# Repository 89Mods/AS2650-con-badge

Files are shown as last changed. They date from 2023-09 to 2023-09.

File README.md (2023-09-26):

## AS2650 Con Badge

Repo containing all the files for my latest con badge, using one of my GFMPW-0 ICs.

`HW` contains the KiCad project for the hardware.

`NB_Firmware` contains the management controller firmware.

`CPLD` contains the Quartus project for the CPLD on the board.

`Verilog` contains a complete Verilog model of the whole board, including the LED screen (requires gtkmm-4.0 to display).

`Software` is the actual meat of the project - all the code running on the badge.

`Bitmaps` contains all image assets to be placed into ROM.

Some misc stuff:

`ObjParser.java` converts .obj 3D model files to the format used by my rasterizer implementation.

`ROM_layout` visualizes the layout of the SPI flash accessible by the AS2650.

`ROMGlue` is a very long script that grabs all the different built binaries and asset files, and puts it also into a single ROM image, according to the documented layout.

`Avali.bin` is the 3D model data rendered by one of the demos.

There is also a (very ugly) Makefile to build parts of the project.

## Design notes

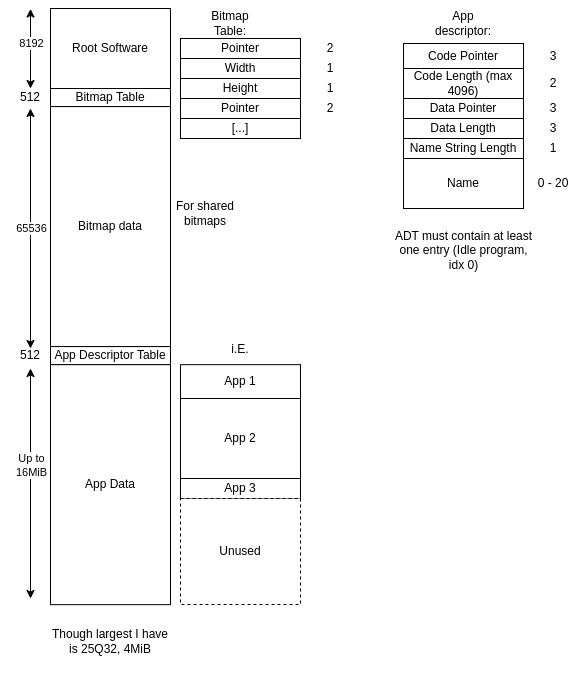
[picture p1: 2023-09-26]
ROM_layout.drawio.png

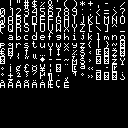
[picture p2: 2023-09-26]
Bitmaps/font.png

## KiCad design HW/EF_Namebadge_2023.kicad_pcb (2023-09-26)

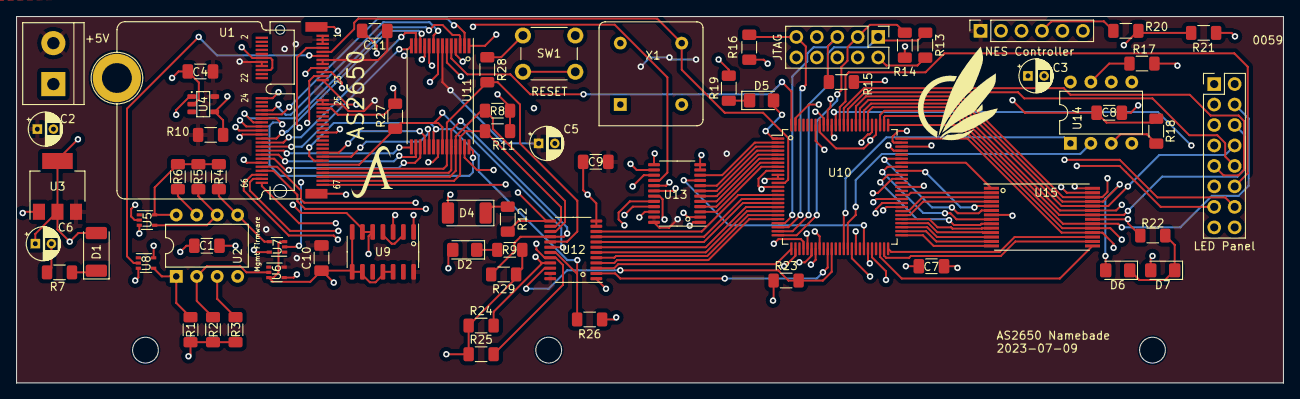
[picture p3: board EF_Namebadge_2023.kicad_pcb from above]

Board: 4 copper layers, 157.2 x 45.5 mm, 71 parts (0 on the bottom side), 124 nets.

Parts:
C1, C4, C7, C8, C9, C10, C11: 0.1µF; C_1206_3216Metric_Pad1.33x1.80mm_HandSolder
C2, C5, C6: 1µF; CP_Radial_D4.0mm_P2.00mm
C3: 10µF; CP_Radial_D4.0mm_P2.00mm
D1, D4: LED; LED_2010_5025Metric_Pad1.52x2.65mm_HandSolder
D2, D5, D6, D7: LED; LED_1206_3216Metric_Pad1.42x1.75mm_HandSolder
H1: MICROMOD-Standoff; MicroMod-Standoff
H2, H3, H4: MountingHole; MountingHole_3.2mm_M3_ISO7380
J1: Screw_Terminal_01x02; TerminalBlock_bornier-2_P5.08mm
J2: JTAG; PinHeader_2x05_P2.54mm_Vertical
J3: LED Panel; PinHeader_2x08_P2.54mm_Vertical
J4: NES Controller; PinSocket_1x06_P2.54mm_Vertical
R1, R2, R4, R5: 100K; R_1206_3216Metric_Pad1.30x1.75mm_HandSolder
R3, R6, R7, R8, R9, R10, R11, R12, R13, R14, R15, R16, R17, R18, R23, R24, R25, R26, R27, R28, R29: 10K; R_1206_3216Metric_Pad1.30x1.75mm_HandSolder
R19, R20, R21, R22: 1K; R_1206_3216Metric_Pad1.30x1.75mm_HandSolder
SW1: SW_Push; SW_PUSH_6mm
U1: AS2650; M.2-CONNECTOR-E
U2, U14: W25Q32FVSS; DIP-8_W7.62mm
U3: AMS1117-3.3; SOT-223-3_TabPin2
U4: MCP1319MT-29LE-OT; PoR_5_SOT23
U5, U6, U7, U8: SN74LV1T34DCK; SOT-353_SC-70-5
U9: 74HC02; SOIC-14_3.9x8.7mm_P1.27mm
U10: EPM240T100; LQFP-100_14x14mm_P0.5mm
U11: AS7C256; TSOP-I-28_11.8x8mm_P0.55mm
U12, U13: SN74LVC8T245; TSSOP-24_4.4x7.8mm_P0.65mm
U15: 61LV256; TSOP-I-28_11.8x8mm_P0.55mm
X1: 25MHz; Oscillator_DIP-8

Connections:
+3V3: C1.1, C3.1, C6.1, C7.2, C8.2, D1.2 (A), J2.4, R1.2, R2.2, R3.2, R4.2, R5.2, R6.2, R14.2, R15.2, R16.2, R17.1, R18.2, R23.1, U2.8 (VCC), U3.2 (VO), U5.5 (VCC), U7.5 (VCC), U8.5 (VCC), U10.9 (VCCIO1), U10.13 (VCCINT), U10.31 (VCCIO1), U10.45 (VCCIO1), U10.59 (VCCIO2), U10.63 (VCCINT), U10.80 (VCCIO2), U10.94 (VCCIO2), U12.1 (Vcca), U13.1 (Vcca), U14.8 (VCC), U15.7 (Vdd), X1.8 (Vcc)
+5V: C2.1, C4.2, C5.1, C9.2, C10.2, C11.2, J1.2, J4.1, R10.2, U1.1 (vccd2), U1.3 (vddio), U1.5 (vdda), U1.13 (vdda2), U1.14 (vccd), U1.15 (vcdd), U1.16 (vddio), U1.33 (vdda1), U1.35 (vccd1), U3.3 (VI), U4.5 (VDD), U6.5 (VCC), U9.14 (VCC), U11.7 (Vcc), U12.23 (Vccb), U12.24 (Vccb), U13.23 (Vccb), U13.24 (Vccb)
A0: U1.62 (mprj_io[20]), U11.17 (A0)
A1: U1.60 (mprj_io[21]), U11.16 (A1)
A2: U1.58 (mprj_io[22]), U11.15 (A2)
A3: U1.56 (mprj_io[23]), U11.14 (A3)
A4: U1.54 (mprj_io[24]), U11.13 (A4)
A5: U1.52 (mprj_io[25]), U11.12 (A5)
A6: U1.50 (mprj_io[26]), U11.11 (A6)
A7: U1.48 (mprj_io[27]), U11.10 (A7)
A8: U1.46 (mprj_io[28]), U11.4 (A8)
A9: U1.44 (mprj_io[29]), U11.3 (A9)
A10: U1.42 (mprj_io[30]), U11.28 (A10)
A11: U1.40 (mprj_io[31]), U11.2 (A11)
A12: U1.38 (mprj_io[32]), U11.9 (A12), U13.16 (B6)
A12_3.3: U10.3 (IO1_3), U13.8 (A6)
A13: U10.100 (IO2_100), U11.5 (A13)
A14: U10.99 (IO2_99), U11.8 (A14)
BUS_DIR: U10.35 (IO1_35), U12.2 (DIR)
DB0: R24.2, U1.59 (mprj_io[5]_ser_rx), U11.18 (I/O0), U12.21 (B1)
DB0_3.3: U10.26 (IO1_26), U12.3 (A1)
DB1: R25.2, U1.61 (mprj_io[6]_ser_tx), U11.19 (I/O1), U12.20 (B2)
DB1_3.3: U10.21 (IO1_21), U12.4 (A2)
DB2: R26.2, U1.63 (mprj_io[7]), U11.20 (I/O2), U12.19 (B3)
DB2_3.3: U10.20 (IO1_20), U12.5 (A3)
DB3: R27.2, U1.65 (mprj_io[8]), U11.22 (I/O3), U12.18 (B4)
DB3_3.3: U10.19 (IO1_19), U12.6 (A4)
DB4: R28.2, U1.67 (mprj_io[9]), U11.23 (I/O4), U12.17 (B5)
DB4_3.3: U10.18 (IO1_18), U12.7 (A5)
DB5: R29.2, U1.69 (mprj_io[10]), U11.24 (I/O5), U12.16 (B6)
DB5_3.3: U10.17 (IO1_17), U12.8 (A6)
DB6: R8.2, U1.71 (mprj_io[11]), U11.25 (I/O6), U12.15 (B7)
DB6_3.3: U10.16 (IO1_16), U12.9 (A7)
DB7: R11.2, U1.73 (mprj_io[12]), U11.26 (I/O7), U12.14 (B8)
DB7_3.3: U10.15 (IO1_15), U12.10 (A8)
DISP_A: J3.10, U10.86 (IO2_86)
DISP_B: J3.9, U10.87 (IO2_87)
DISP_C: J3.12, U10.88 (IO2_88)
DISP_CLK: J3.14, U10.73 (IO2_73)
DISP_D: J3.11, U10.89 (IO2_89)
DISP_OE: J3.16, U10.74 (IO2_74)
DISP_STB: J3.13, U10.72 (IO2_72)
D/~C: U1.74 (mprj_io[14]), U13.21 (B1)
D/~C_3.3: U10.8 (IO1_8), U13.3 (A1)
FIRM_CS: R1.1, U2.1 (~CS), U8.4 (Y)
FIRM_SCK: R5.1, U2.6 (SCK), U5.4 (Y)
FIRM_SI: R4.1, U2.5 (SI(D0)), U7.4 (Y)
FIRM_SO: R2.1, U2.2 (SO(D1)), U6.2 (A)
Flag: D2.2 (A), U1.64 (mprj_io[19])
GND: C1.2, C2.2, C3.2, C4.1, C5.2, C6.2, C7.1, C8.1, C9.1, C10.1, C11.1, J1.1, J2.2, J2.10, J3.3, J3.7, J3.15, J4.5, J4.6, R7.2, R8.1, R9.2, R11.1, R12.2, R13.2, R19.2, R21.1, R22.2, R24.1, R25.1, R26.1, R27.1, R28.1, R29.1, SW1.1, U1.12 (GND), U1.18 (GND), U1.37 (GND), U1.A1 (GND), U1.A2 (GND), U2.4 (GND), U3.1 (GND), U4.2 (VSS), U5.3 (GND), U6.3 (GND), U7.3 (GND), U8.3 (GND), U9.7 (GND), U9.8, U9.9, U9.11, U9.12, U10.10 (GNDIO), U10.11 (GNDINT), U10.32 (GNDIO), U10.46 (GNDIO), U10.60 (GNDIO), U10.65 (GNDINT), U10.79 (GNDIO), U10.93 (GNDIO), U11.21 (GND), U12.11 (GND), U12.12 (GND), U12.13 (GND), U13.2 (DIR), U13.11 (GND), U13.12 (GND), U13.13 (GND), U13.22 (~OE), U14.4 (GND), U15.21 (GND), U15.27 (~CE), X1.4 (GND)
LVL_SHIFT_EN: R23.2, U10.36 (IO1_36), U12.22 (~OE)
M/~IO: U1.72 (mprj_io[15]), U13.20 (B2)
M/~IO_3.3: U10.7 (IO1_7), U13.4 (A2)
NES_CLK: J4.2, U10.29 (IO1_29)
NES_DATA: R20.1, R21.2, U10.33 (IO1_33)
NES_LATCH: J4.3, U10.30 (IO1_30)
unnamed: D1.1 (K), R7.1
unnamed: D2.1 (K), R9.1
unnamed: D4.1 (K), R12.1
unnamed: D5.2 (A), U10.1 (IO2_1)
unnamed: D5.1 (K), R19.1
unnamed: D6.1 (K), D7.1 (K), R22.1
unnamed: J2.1, R13.1, U10.24 (TCK)
unnamed: J2.3, R14.1, U10.25 (TDO)
unnamed: J2.5, R15.1, U10.22 (TMS)
unnamed: J2.9, R16.1, U10.23 (TDI)
unnamed: J4.4, R20.2
unnamed: U1.11 (Caravel_CSB), U8.2 (A)
unnamed: U1.17 (Caravel_D0), U7.2 (A)
unnamed: U1.19 (Caravel_D1), U6.4 (Y)
unnamed: U1.23 (Caravel_SCK), U5.2 (A)
unnamed: U1.7 (~RST), U9.1
unnamed: R6.1, U2.7 (~HOLD(D3))
unnamed: R3.1, U2.3 (~WP(D2))
unnamed: R10.1, SW1.2, U4.4 (~MR)
unnamed: U9.2, U9.4
unnamed: U10.2 (IO1_2), U13.10 (A8)
unnamed: R17.2, U14.7 (~HOLD(D3))
unnamed: R18.1, U14.3 (~WP(D2))
OPREQ: U1.68 (mprj_io[17]), U13.18 (B4)
OPREQ_3.3: U10.5 (IO1_5), U13.6 (A4)
POR: U4.1 (~RST), U9.5, U9.6, U13.15 (B7)
POR_3.3: U10.44 (IO1_44/DEV_CLRn), U13.9 (A7)
R/~W: U1.66 (mprj_io[18]), U13.17 (B5)
R/~W_3.3: U10.4 (IO1_4), U13.7 (A5)
SPI_SCK: U10.41 (IO1_41), U14.6 (SCK)
SPI_SI: U10.40 (IO1_40), U14.2 (SO(D1))
SPI_SO: U10.42 (IO1_42), U14.5 (SI(D0))
Sense: U1.75 (mprj_io[13]), U10.27 (IO1_27)
VRAM_AD0: U10.50 (IO1_50), U15.17 (A0)
VRAM_AD1: U10.49 (IO1_49), U15.16 (A1)
VRAM_AD2: U10.48 (IO1_48), U15.15 (A2)
VRAM_AD3: U10.51 (IO1_51), U15.14 (A3)
VRAM_AD4: U10.52 (IO2_52), U15.13 (A4)
VRAM_AD5: U10.53 (IO2_53), U15.12 (A5)
VRAM_AD6: U10.54 (IO2_54), U15.11 (A6)
VRAM_AD7: U10.55 (IO2_55), U15.10 (A7)
VRAM_AD8: U10.56 (IO2_56), U15.4 (A8)
VRAM_AD9: U10.57 (IO2_57), U15.3 (A9)
VRAM_AD10: U10.58 (IO2_58), U15.28 (A10)
VRAM_AD11: U10.61 (IO2_61), U15.2 (A11)
VRAM_AD12: U10.66 (IO2_66), U15.9 (A12)
VRAM_AD13: U10.67 (IO2_67), U15.5 (A13)
VRAM_AD14: U10.68 (IO2_68), U15.8 (A14)
VRAM_D0: J3.2, U10.75 (IO2_75), U15.18 (IO0)
VRAM_D1: J3.1, U10.76 (IO2_76), U15.19 (IO1)
VRAM_D2: J3.4, U10.77 (IO2_77), U15.20 (IO2)
VRAM_D3: J3.6, U10.78 (IO2_78), U15.22 (IO3)
VRAM_D4: J3.5, U10.81 (IO2_81), U15.23 (IO4)
VRAM_D5: J3.8, U10.82 (IO2_82), U15.24 (IO5)
VRAM_D6: D6.2 (A), U10.83 (IO2_83), U15.25 (IO6)
VRAM_D7: D7.2 (A), U10.84 (IO2_84), U15.26 (IO7)
WRP: U1.70 (mprj_io[16]), U13.19 (B3)
WRP_3.3: U10.6 (IO1_6), U13.5 (A3)
cpld_rst: U1.32 (mprj_io[35]), U13.14 (B8)
crvl_led: D4.2 (A), U1.49 (mprj_io[0])
gpio: U1.21 (gpio), U9.3
xclk: U1.9 (xclk), U10.12 (IO1_12/GCLK0), X1.5 (OUT)
~RAM_CE: U10.90 (IO2_90), U11.27 (~CE)
~RAM_OE: U10.91 (IO2_91), U11.1 (~OE)
~RAM_WE: U10.92 (IO2_92), U11.6 (~WE)
~SPI_CS: U10.39 (IO1_39), U14.1 (~CS)
~VRAM_OE: U10.69 (IO2_69), U15.1 (~OE)
~VRAM_WE: U10.70 (IO2_70), U15.6 (~WE)

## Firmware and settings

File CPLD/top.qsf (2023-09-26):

# -------------------------------------------------------------------------- #
#
# Copyright (C) 2023  Intel Corporation. All rights reserved.
# Your use of Intel Corporation's design tools, logic functions 
# and other software and tools, and any partner logic 
# functions, and any output files from any of the foregoing 
# (including device programming or simulation files), and any 
# associated documentation or information are expressly subject 
# to the terms and conditions of the Intel Program License 
# Subscription Agreement, the Intel Quartus Prime License Agreement,
# the Intel FPGA IP License Agreement, or other applicable license
# agreement, including, without limitation, that your use is for
# the sole purpose of programming logic devices manufactured by
# Intel and sold by Intel or its authorized distributors.  Please
# refer to the applicable agreement for further details, at
# https://fpgasoftware.intel.com/eula.
#
# -------------------------------------------------------------------------- #
#
# Quartus Prime
# Version 22.1std.1 Build 917 02/14/2023 SC Lite Edition
# Date created = 17:04:29  June 30, 2023
#
# -------------------------------------------------------------------------- #
#
# Notes:
#
# 1) The default values for assignments are stored in the file:
#		top_assignment_defaults.qdf
#    If this file doesn't exist, see file:
#		assignment_defaults.qdf
#
# 2) Intel recommends that you do not modify this file. This
#    file is updated automatically by the Quartus Prime software
#    and any changes you make may be lost or overwritten.
#
# -------------------------------------------------------------------------- #


set_global_assignment -name FAMILY "MAX II"
set_global_assignment -name DEVICE EPM240T100C5
set_global_assignment -name TOP_LEVEL_ENTITY top
set_global_assignment -name ORIGINAL_QUARTUS_VERSION 22.1STD.1
set_global_assignment -name PROJECT_CREATION_TIME_DATE "17:04:29  JUNE 30, 2023"
set_global_assignment -name LAST_QUARTUS_VERSION "22.1std.2 Lite Edition"
set_global_assignment -name PROJECT_OUTPUT_DIRECTORY output_files
set_global_assignment -name MIN_CORE_JUNCTION_TEMP 0
set_global_assignment -name MAX_CORE_JUNCTION_TEMP 85
set_global_assignment -name DEVICE_FILTER_PACKAGE TQFP
set_global_assignment -name DEVICE_FILTER_PIN_COUNT 100
set_global_assignment -name ERROR_CHECK_FREQUENCY_DIVISOR "-1"
set_global_assignment -name POWER_EXT_SUPPLY_VOLTAGE_TO_REGULATOR 3.3V
set_location_assignment PIN_5 -to opreq
set_location_assignment PIN_4 -to rw
set_location_assignment PIN_6 -to wrp
set_location_assignment PIN_12 -to clk
set_location_assignment PIN_15 -to dbus[7]
set_location_assignment PIN_16 -to dbus[6]
set_location_assignment PIN_17 -to dbus[5]
set_location_assignment PIN_18 -to dbus[4]
set_location_assignment PIN_19 -to dbus[3]
set_location_assignment PIN_20 -to dbus[2]
set_location_assignment PIN_21 -to dbus[1]
set_location_assignment PIN_26 -to dbus[0]
set_instance_assignment -name IO_STANDARD "3.3-V LVTTL" -to A12
set_instance_assignment -name IO_STANDARD "3.3-V LVTTL" -to DISP_addr[1]
set_location_assignment PIN_3 -to A12
set_location_assignment PIN_100 -to A13
set_location_assignment PIN_99 -to A14
set_location_assignment PIN_86 -to DISP_addr[0]
set_location_assignment PIN_87 -to DISP_addr[1]
set_location_assignment PIN_88 -to DISP_addr[2]
set_location_assignment PIN_89 -to DISP_addr[3]
set_location_assignment PIN_73 -to DISP_clk
set_location_assignment PIN_74 -to DISP_oeb
set_location_assignment PIN_72 -to DISP_stb
set_location_assignment PIN_29 -to NES_clk
set_location_assignment PIN_33 -to NES_data
set_location_assignment PIN_91 -to RAM_oeb
set_location_assignment PIN_90 -to RAM_ceb
set_location_assignment PIN_92 -to RAM_web
set_location_assignment PIN_27 -to sense
set_location_assignment PIN_7 -to m_io
set_location_assignment PIN_36 -to lvl_shift_enb
set_location_assignment PIN_2 -to cpld_rst
set_location_assignment PIN_8 -to d_c
set_location_assignment PIN_35 -to bus_dir
set_location_assignment PIN_70 -to VRAM_web
set_location_assignment PIN_69 -to VRAM_oeb
set_location_assignment PIN_84 -to VRAM_data[7]
set_location_assignment PIN_83 -to VRAM_data[6]
set_location_assignment PIN_82 -to VRAM_data[5]
set_location_assignment PIN_81 -to VRAM_data[4]
set_location_assignment PIN_78 -to VRAM_data[3]
set_location_assignment PIN_77 -to VRAM_data[2]
set_location_assignment PIN_76 -to VRAM_data[1]
set_location_assignment PIN_75 -to VRAM_data[0]
set_location_assignment PIN_68 -to VRAM_addr[14]
set_location_assignment PIN_67 -to VRAM_addr[13]
set_location_assignment PIN_66 -to VRAM_addr[12]
set_location_assignment PIN_44 -to POR
set_location_assignment PIN_30 -to NES_latch
set_location_assignment PIN_39 -to SPI_csb
set_location_assignment PIN_41 -to SPI_sck
set_location_assignment PIN_40 -to SPI_si
set_location_assignment PIN_42 -to SPI_so
set_location_assignment PIN_61 -to VRAM_addr[11]
set_location_assignment PIN_58 -to VRAM_addr[10]
set_location_assignment PIN_57 -to VRAM_addr[9]
set_location_assignment PIN_56 -to VRAM_addr[8]
set_location_assignment PIN_55 -to VRAM_addr[7]
set_location_assignment PIN_54 -to VRAM_addr[6]
set_location_assignment PIN_53 -to VRAM_addr[5]
set_location_assignment PIN_52 -to VRAM_addr[4]
set_location_assignment PIN_51 -to VRAM_addr[3]
set_location_assignment PIN_48 -to VRAM_addr[2]
set_location_assignment PIN_49 -to VRAM_addr[1]
set_location_assignment PIN_50 -to VRAM_addr[0]
set_location_assignment PIN_1 -to LED
set_instance_assignment -name IO_STANDARD "3.3-V LVTTL" -to RAM_ceb
set_instance_assignment -name IO_STANDARD "3.3-V LVTTL" -to RAM_oeb
set_instance_assignment -name IO_STANDARD "3.3-V LVCMOS" -to RAM_web
set_instance_assignment -name IO_STANDARD "3.3-V LVCMOS" -to A13
set_instance_assignment -name IO_STANDARD "3.3-V LVCMOS" -to A14
set_instance_assignment -name IO_STANDARD "3.3-V LVTTL" -to dbus[7]
set_instance_assignment -name IO_STANDARD "3.3-V LVTTL" -to dbus[6]
set_instance_assignment -name IO_STANDARD "3.3-V LVTTL" -to dbus[5]
set_instance_assignment -name IO_STANDARD "3.3-V LVTTL" -to dbus[4]
set_instance_assignment -name IO_STANDARD "3.3-V LVTTL" -to dbus[3]
set_instance_assignment -name IO_STANDARD "3.3-V LVTTL" -to dbus[2]
set_instance_assignment -name IO_STANDARD "3.3-V LVTTL" -to dbus[1]
set_instance_assignment -name IO_STANDARD "3.3-V LVTTL" -to dbus
set_global_assignment -name SDC_FILE top.out.sdc
set_global_assignment -name VERILOG_FILE top.v
set_global_assignment -name POWER_PRESET_COOLING_SOLUTION "NO HEAT SINK WITH STILL AIR"

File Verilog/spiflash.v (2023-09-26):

`default_nettype none
/*
 *  SPDX-FileCopyrightText: 2017 Clifford Wolf
 *
 *  PicoSoC - A simple example SoC using PicoRV32
 *
 *  Copyright (C) 2017  Clifford Wolf <clifford@clifford.at>
 *
 *  Permission to use, copy, modify, and/or distribute this software for any
 *  purpose with or without fee is hereby granted, provided that the above
 *  copyright notice and this permission notice appear in all copies.
 *
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
 *  SPDX-License-Identifier: ISC
 */

`timescale 1 ns / 1 ps

//
// Simple SPI flash simulation model
//
// This model samples io input signals 1ns before the SPI clock edge and
// updates output signals 1ns after the SPI clock edge.
//
// Supported commands:
//    AB, B9, FF, 03, BB, EB, ED
//
// Well written SPI flash data sheets:
//    Cypress S25FL064L http://www.cypress.com/file/316661/download
//    Cypress S25FL128L http://www.cypress.com/file/316171/download
//

module spiflash #(
	parameter FILENAME = "../software.txt"
)(
	input csb,
	input clk,
	inout io0, // MOSI
	inout io1, // MISO
	inout io2,
	inout io3
);
	localparam verbose = 0;
	localparam integer latency = 8;
	
	reg [7:0] buffer;
	reg [3:0] reset_count = 0;
	reg [3:0] reset_monitor = 0;
	integer bitcount = 0;
	integer bytecount = 0;
	integer dummycount = 0;

	reg [7:0] spi_cmd;
	reg [7:0] xip_cmd = 0;
	reg [23:0] spi_addr;

	reg [7:0] spi_in;
	reg [7:0] spi_out;
	reg spi_io_vld;

	reg powered_up = 0;

	localparam [3:0] mode_spi         = 1;
	localparam [3:0] mode_dspi_rd     = 2;
	localparam [3:0] mode_dspi_wr     = 3;
	localparam [3:0] mode_qspi_rd     = 4;
	localparam [3:0] mode_qspi_wr     = 5;
	localparam [3:0] mode_qspi_ddr_rd = 6;
	localparam [3:0] mode_qspi_ddr_wr = 7;

	reg [3:0] mode = 0;
	reg [3:0] next_mode = 0;

	reg io0_oe = 0;
	reg io1_oe = 0;
	reg io2_oe = 0;
	reg io3_oe = 0;

	reg io0_dout = 0;
	reg io1_dout = 0;
	reg io2_dout = 0;
	reg io3_dout = 0;

	assign io0 = io0_oe ? io0_dout : 1'bz;
	assign io1 = io1_oe ? io1_dout : 1'bz;
	assign io2 = io2_oe ? io2_dout : 1'bz;
	assign io3 = io3_oe ? io3_dout : 1'bz;

	wire io0_delayed;
	wire io1_delayed;
	wire io2_delayed;
	wire io3_delayed;

	assign io0_delayed = io0;
	assign io1_delayed = io1;
	assign io2_delayed = io2;
	assign io3_delayed = io3;

	// 16 MB (128Mb) Flash
	reg [7:0] memory [0:16*1024*1024-1];

	initial begin
		//$display("Memory 5 bytes = 0x%02x 0x%02x 0x%02x 0x%02x 0x%02x",
		//	memory[1048576], memory[1048577], memory[1048578],
		//	memory[1048579], memory[1048580]);
		$display("Reading %s",  FILENAME);
		$readmemh(FILENAME, memory);
		$display("%s loaded into memory", FILENAME);
		$display("Memory 5 bytes = 0x%02x 0x%02x 0x%02x 0x%02x 0x%02x",
			memory[0], memory[1], memory[2],
			memory[3], memory[4]);
	end

	task spi_action;
		begin
			spi_in = buffer;

			if (bytecount == 1) begin
				spi_cmd = buffer;

				if (spi_cmd == 8'h ab)
					powered_up = 1;

				if (spi_cmd == 8'h b9)
					powered_up = 0;

				if (spi_cmd == 8'h ff)
					xip_cmd = 0;
				
			end
			if (spi_cmd == 8'h 90 && bytecount >= 4) buffer = 8'hAB; //Different ID from real chip, so CPU knows its in a simulation
			if (powered_up && spi_cmd == 'h 03) begin
				if (bytecount == 2)
					spi_addr[23:16] = buffer;

				if (bytecount == 3)
					spi_addr[15:8] = buffer;

				if (bytecount == 4)
					spi_addr[7:0] = buffer;

				if (bytecount >= 4) begin
					buffer = memory[spi_addr];
					spi_addr = spi_addr + 1;
				end
			end

			if (powered_up && spi_cmd == 'h bb) begin
				if (bytecount == 1)
					mode = mode_dspi_rd;

				if (bytecount == 2)
					spi_addr[23:16] = buffer;

				if (bytecount == 3)
					spi_addr[15:8] = buffer;

				if (bytecount == 4)
					spi_addr[7:0] = buffer;

				if (bytecount == 5) begin
					xip_cmd = (buffer == 8'h a5) ? spi_cmd : 8'h 00;
					mode = mode_dspi_wr;
					dummycount = latency;
				end

				if (bytecount >= 5) begin
					buffer = memory[spi_addr];
					spi_addr = spi_addr + 1;
				end
			end

			if (powered_up && spi_cmd == 'h eb) begin
				if (bytecount == 1)
					mode = mode_qspi_rd;

				if (bytecount == 2)
					spi_addr[23:16] = buffer;

				if (bytecount == 3)
					spi_addr[15:8] = buffer;

				if (bytecount == 4)
					spi_addr[7:0] = buffer;

				if (bytecount == 5) begin
					xip_cmd = (buffer == 8'h a5) ? spi_cmd : 8'h 00;
					mode = mode_qspi_wr;
					dummycount = latency;
				end

				if (bytecount >= 5) begin
					buffer = memory[spi_addr];
					spi_addr = spi_addr + 1;
				end
			end

			if (powered_up && spi_cmd == 'h ed) begin
				if (bytecount == 1)
					next_mode = mode_qspi_ddr_rd;

				if (bytecount == 2)
					spi_addr[23:16] = buffer;

				if (bytecount == 3)
					spi_addr[15:8] = buffer;

				if (bytecount == 4)
					spi_addr[7:0] = buffer;

				if (bytecount == 5) begin
					xip_cmd = (buffer == 8'h a5) ? spi_cmd : 8'h 00;
					mode = mode_qspi_ddr_wr;
					dummycount = latency;
				end

				if (bytecount >= 5) begin
					buffer = memory[spi_addr];
					spi_addr = spi_addr + 1;
				end
			end

			spi_out = buffer;
			spi_io_vld = 1;

			if (verbose) begin
				if (bytecount == 1)
					$write("<SPI-START>");
				$write("<SPI:%02x:%02x>", spi_in, spi_out);
			end

		end
	endtask

	task ddr_rd_edge;
		begin
			buffer = {buffer, io3_delayed, io2_delayed, io1_delayed, io0_delayed};
			bitcount = bitcount + 4;
			if (bitcount == 8) begin
				bitcount = 0;
				bytecount = bytecount + 1;
				spi_action;
			end
		end
	endtask

	task ddr_wr_edge;
		begin
			io0_oe = 1;
			io1_oe = 1;
			io2_oe = 1;
			io3_oe = 1;

			io0_dout = buffer[4];
			io1_dout = buffer[5];
			io2_dout = buffer[6];
			io3_dout = buffer[7];

			buffer = {buffer, 4'h 0};
			bitcount = bitcount + 4;
			if (bitcount == 8) begin
				bitcount = 0;
				bytecount = bytecount + 1;
				spi_action;
			end
		end
	endtask

	always @(csb) begin
		if (csb) begin
			if (verbose) begin
				$display("");
				$fflush;
			end
			buffer = 0;
			bitcount = 0;
			bytecount = 0;
			mode = mode_spi;
			io0_oe = 0;
			io1_oe = 0;
			io2_oe = 0;
			io3_oe = 0;

			// Handle MBR.  If in XIP continuous mode, the following
			// 8 clock cycles are normally not expected to be a command.
			// If followed by CSB high, however, if the address bits
			// are consistent with io0 == 1 for 8 clk cycles, then an
			// MBR has been issued and the system must exit XIP
			// continuous mode.
			if (xip_cmd == 8'hbb || xip_cmd == 8'heb
					|| xip_cmd == 8'hed) begin
				if (reset_count == 4'h8 && reset_monitor == 4'h8) begin
					xip_cmd = 8'h00;
					spi_cmd = 8'h03;
				end
			end
		end else
		if (xip_cmd) begin
			buffer = xip_cmd;
			bitcount = 0;
			bytecount = 1;
			spi_action;
		end
	end

	always @(posedge clk or posedge csb) begin
		if (csb == 1'b1) begin
			reset_count = 0;
			reset_monitor = 0;
		end else begin
			if (reset_count < 4'h9) begin
				reset_count = reset_count + 1;
				if (io0_delayed == 1'b1) begin
				    reset_monitor = reset_monitor + 1;
				end
			end
		end
	end
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
